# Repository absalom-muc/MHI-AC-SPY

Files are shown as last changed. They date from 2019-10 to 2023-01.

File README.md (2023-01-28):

# MHI-AC-SPY

**This repository is no longer maintained and is therefore archived. An improved version including writing to the air conditioner is [here](https://github.com/absalom-muc/MHI-AC-Ctrl)**

The version here should be only used as a demonstration how to program the HW SPI of the ESP8266 for receiving data.

The program reads data (e.g. room temperature, fan status etc.) from a Mitsubishi Heavy Industries (MHI)
air conditioner (AC) via SPI and sends the data via MQTT. The AC is the SPI master and the ESP8266 is the SPI slave.
So far only reading from the AC is supported. (but writing is planned for the future)
The program has a draft status and your input is welcome.
My target is to read and write data with an ESP8266.

# Attention:
You have to open the indoor unit to have access to the SPI. Opening of the indoor unit should be done by 
a qualified professional because faulty handling may cause leakage of water, electric shock or fire!

# Prerequisites:
For use of the program you have to connect your ESP8266 (I use a LOLIN(WEMOS) D1 R2 & mini with 80 MHz) via a
cable connector to your air conditioner. This has to be a split device (separated indoor and outdoor unit).
I assume that all indoor units of the type SRC xx ZS-S are supported. I use the indoor unit SRK 35 ZS-S and the outdoor unit SRC 35 ZS-S.
  
# Installing:

## Hardware:
The ESP8266 is powered from the AC via DC-DC (12V -> 5V) converter
The ESP8266 SPI signals SCL (SPI clock) and MOSI (Master Out Slave In) signals are connected via a voltage divider with the AC. But after gaining some experiences I recommend to use a voltage level shifter instead of a voltage divider.

## Software:
The program uses the [MQTT client library](https://github.com/knolleary/pubsubclient) from Nick O'Leary (knolleary). Thank you Nick - great work!
Please check his GitHub page to see how to install it.
Dwonload MHI-SPI.ino and adapt ssid, password and the MQTT server data in the row MQTTclient.setServer("ds218p", 1883);

# License
This project is licensed under the MIT License - see the LICENSE.md file for details

# Acknowledgments
The coding of the SPI protocol of the AC is a nightmare. Without [rjdekker's MHI2MQTT](https://github.com/rjdekker/MHI2MQTT) I had no chance to understand the protocol! Unfortunatelly rjdekker is not longer active on GitHub. He used an Arduino plus an ESP8266 for his project.

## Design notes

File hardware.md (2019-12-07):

# Hardware
**After gaining some experience I recommend to use a voltage level shifter instead of the resistor based voltage divider, please see [here](https://github.com/absalom-muc/MHI-AC-Ctrl)**

## Schematic
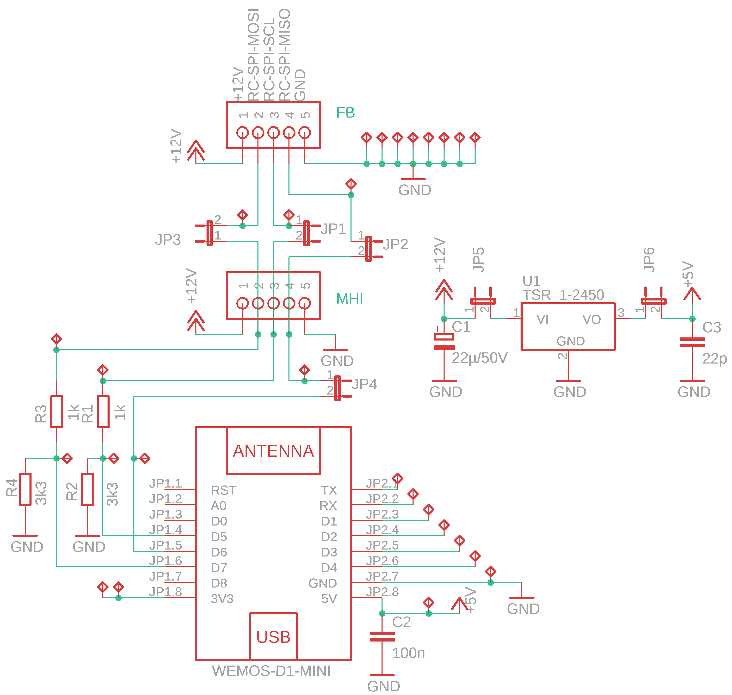
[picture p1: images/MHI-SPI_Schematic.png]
schematic


## Connector
The AC provides the signals via the CNS connector. It has 5 pins with a pitch of 2 mm (0.079''). It is out of the [PH series from JST](http://www.jst-mfg.com/product/detail_e.php?series=199). The position of the connector is visible on the following photo of the indoor unit PCB.
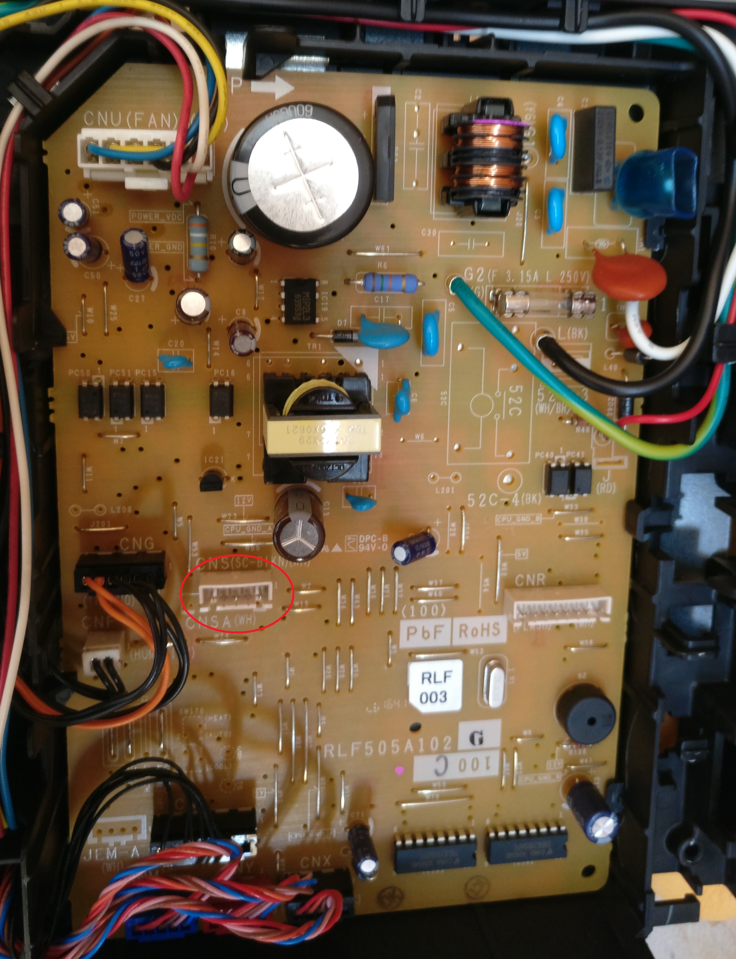
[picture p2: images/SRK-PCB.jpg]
Indoor PCB

**Opening of the indoor unit should be done by a qualified professional because faulty handling may cause leakage of water, electric shock or fire!**

## Power Supply
The connector provides +12V. The DC-DC converter [TSR 1-2450](https://www.tracopower.com/products/browse-by-category/find/tsr-1/3/) is used to convert it to +5V.

## MHI-SPI Testboard
The [Eagle](https://www.autodesk.com/products/eagle/overview) files (schematic & PCB) for the testboard are located in the sub-folder [eagle](/eagle). On the PCB are located many jumper and test pins to enable simple connections to measuring devices.

The following photo shows the assembled testboard.
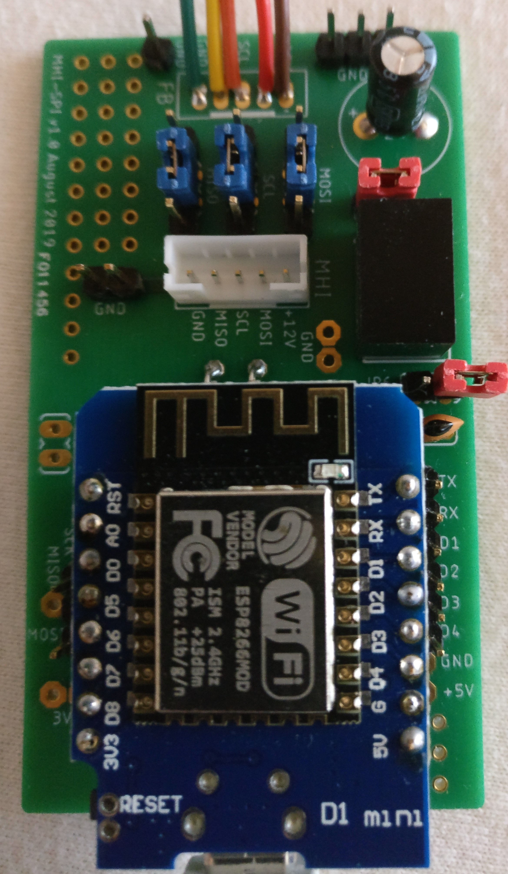
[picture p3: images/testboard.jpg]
Testboard

The upper colored cables are connected to an AC remote control. The JST connector is connected to the MHI AC.

## Signal Connection
SCK is connected via a voltage divider with D5 (GPIO14) and MOSI is connected via a voltage divider with D7 (GPIO13) of ESP8266.

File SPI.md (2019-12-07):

# SPI Bus
**This version is outdated, better check the version [here](https://github.com/absalom-muc/MHI-AC-Ctrl)**
## Interface
The AC is the SPI master and the ESP8266 is the SPI slave. MHI uses the signals SCK, MOSI, MISO.  A slave select signal is not supported.

Name | Function |input/output
------------ | ------------- |--------------
SCK | serial clock | Clock output for AC, input for ESP8266
MOSI | Master Out, Slave In | Data output for MHI, input for ESP8266
MISO | Master In, Slave Out | Input for MHI, output for ESP8266

## Protocol
Clock polarity: CPOL=1 => clock idles at 1, and each cycle consists of a pulse of 0
Clock timing: CPHA=1 => data is captures with the rising clock edge, data changes with the falling edge
## Timing
A byte consists of 8 bits. SCK has a frequency of 32kHz. One bit takes 31.25µs, so one byte takes 8x31.25µs=250µs. There is a pause of 250µs between two bytes.
A frame consists of 20 bytes. A frame consumes 20x2x250µs=10ms. Between 2 frames is a pause of 40ms. So 20 frames per second will be transmitted. The following oscilloscope screenshot shows 3 bytes:
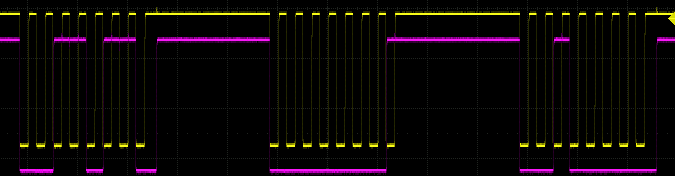
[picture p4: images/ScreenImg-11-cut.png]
SPI timing


Yellow: SCK; Purple: MOSI
# SPI Frame
A frame starts with three signature bytes, followed by 15 data bytes and 2 bytes for a checksum. The following table shows the content of a frame.
## Signature
The MOSI signature bytes indicate the start of a frame with the 3 bytes 0x6c, 0x80, 0x04.
For MISO seems to be more than one signature, usually it is 0xa9, 0x00, 0x07.

## Data
The following clauses describe the MOSI decoding for power, mode, fan, vanes, temperature setpoint and the room temperature
### Power
Power status is coded in MOSI data byte 0 (bit 0).

data byte 0	| Function
---- | -----
Bit 0| Power
0 | off
1 | on

### Mode
The mode is coded in MOSI data byte 0 (bit 4 ... 2).
<table style="width: 273px; height: 68px;">
<thead>
<tr>
<td style="width: 66.9667px;" colspan="3"><strong>data byte 0</strong></td>
<td style="width: 66.9667px;"><strong>Function</strong></td>
</tr>
</thead>
<tbody>
<tr>
<td style="width: 66.9667px;">bit 4</td>
<td style="width: 71.4333px;">bit 3</td>
<td style="width: 66.9667px;">bit 2</td>
<td style="width: 66.9667px;">Mode</td>
</tr>
<tr>
<td style="width: 66.9667px;">0</td>
<td style="width: 71.4333px;">0</td>
<td style="width: 66.9667px;">0</td>
<td style="width: 66.9667px;">Auto</td>
</tr>
<tr>
<td style="width: 66.9667px;">0</td>
<td style="width: 71.4333px;">0</td>
<td style="width: 66.9667px;">1</td>
<td style="width: 66.9667px;">Dry</td>
</tr>
<tr>
<td style="width: 66.9667px;">0</td>
<td style="width: 71.4333px;">1</td>
<td style="width: 66.9667px;">0</td>
<td style="width: 66.9667px;">Cool</td>
</tr>
<tr>
<td style="width: 66.9667px;">0</td>
<td style="width: 71.4333px;">1</td>
<td style="width: 66.9667px;">1</td>
<td style="width: 66.9667px;">Fan</td>
</tr>
<td style="width: 66.9667px;">1</td>
<td style="width: 71.4333px;">0</td>
<td style="width: 66.9667px;">0</td>
<td style="width: 66.9667px;">Heat</td>
</tr>
</tbody>
</table>

### Fan
The fan level is coded in MOSI data byte 1 bit [1:0] and in data byte 6 (bit 6).
<table style="width: 273px; height: 68px;">
<thead>
<tr>
<td style="width: 66.9667px;" colspan="2"><strong>data byte 1</strong></td>
<td style="width: 66.9667px;"><strong>data byte 6</strong></td>
<td style="width: 66.9667px;"><strong>Function</strong></td>
</tr>
</thead>
<tbody>
<tr>
<td style="width: 66.9667px;">bit 1</td>
<td style="width: 71.4333px;">bit 0</td>
<td style="width: 66.9667px;">bit 6</td>
<td style="width: 66.9667px;">Fan</td>
</tr>
<tr>
<td style="width: 66.9667px;">0</td>
<td style="width: 71.4333px;">0</td>
<td style="width: 66.9667px;">0</td>
<td style="width: 66.9667px;">1</td>
</tr>
<tr>
<td style="width: 66.9667px;">0</td>
<td style="width: 71.4333px;">1</td>
<td style="width: 66.9667px;">0</td>
<td style="width: 66.9667px;">2</td>
</tr>
<tr>
<td style="width: 66.9667px;">1</td>
<td style="width: 71.4333px;">0</td>
<td style="width: 66.9667px;">0</td>
<td style="width: 66.9667px;">3</td>
</tr>
<tr>
<td style="width: 66.9667px;">x</td>
<td style="width: 71.4333px;">x</td>
<td style="width: 66.9667px;">1</td>
<td style="width: 66.9667px;">4</td>
</tr>
</tbody>
</table>

### Vanes
The vanes up/down level is coded in MOSI data byte 1 bit [5:4] and in data byte 0 (bit 6).
<table style="width: 273px; height: 68px;">
<thead>
<tr>
<td style="width: 66.9667px;" colspan="2"><strong>data byte 1</strong></td>
<td style="width: 66.9667px;"><strong>data byte 0</strong></td>
<td style="width: 66.9667px;"><strong>Function</strong></td>
</tr>
</thead>
<tbody>
<tr>
<td style="width: 66.9667px;">bit 5</td>
<td style="width: 71.4333px;">bit 4</td>
<td style="width: 66.9667px;">bit 6</td>
<td style="width: 66.9667px;">Vanes (up/down)</td>
</tr>
<tr>
<td style="width: 66.9667px;">0</td>
<td style="width: 71.4333px;">0</td>
<td style="width: 66.9667px;">0</td>
<td style="width: 66.9667px;">1</td>
</tr>
<tr>
<td style="width: 66.9667px;">0</td>
<td style="width: 71.4333px;">1</td>
<td style="width: 66.9667px;">0</td>
<td style="width: 66.9667px;">2</td>
</tr>
<tr>
<td style="width: 66.9667px;">1</td>
<td style="width: 71.4333px;">0</td>
<td style="width: 66.9667px;">0</td>
<td style="width: 66.9667px;">3</td>
</tr>
<tr>
<td style="width: 66.9667px;">1</td>
<td style="width: 71.4333px;">1</td>
<td style="width: 66.9667px;">0</td>
<td style="width: 66.9667px;">4</td>
</tr>
<tr>
<td style="width: 66.9667px;">x</td>
<td style="width: 71.4333px;">x</td>
<td style="width: 66.9667px;">1</td>
<td style="width: 66.9667px;">swing</td>
</tr>
</tbody>
</table>
Vanes status is not updated when using IR remote control!

### Room temperature
The room temperature is coded in MOSI data byte 3, bit [7:0] according to the  formula T[°C]=(db3[7:0]-61)/4
The resolution is 0.25°C. But for displaying the room temperature you shouldn't use this resolution to prevent displaying the toggling of the least significant bit.

### Temperature setpoint
The temperature setpoint is coded in MOSI data byte 2, bit [6:0] according to the formula T[°C]=db2[6:0]/2
The resolution of 0.5°C is supported by the wired remote control [RC-E5](https://www.mhi-mth.co.jp/en/products/pdf/pjz012a087b_german.pdf). The IR remote control supports a resolution of 1°C only.

## Checksum
The checksum is calculated by the sum of the signature bytes plus the databytes. The low byte of the checksum is stored at byte position 18 and the low byte of the checksum is stored at byte position 19. Maximum value of the checksum is 0x0fe1. Therefore bit [7:4] of the checksum high byte is always 0.

## Variants
**The following chapter is in draft status!**
Different variants are possible when a remote control is connected via SPI. The MISO frame (data from RC to MHI-AC) requests data. The variant of the data is identified via MISO-db9. MHI-AC answers with the same value in MOSI-db9 (but only when bit2 of MISO-db14 is set).

The following screenshot shows some SPI traffic:
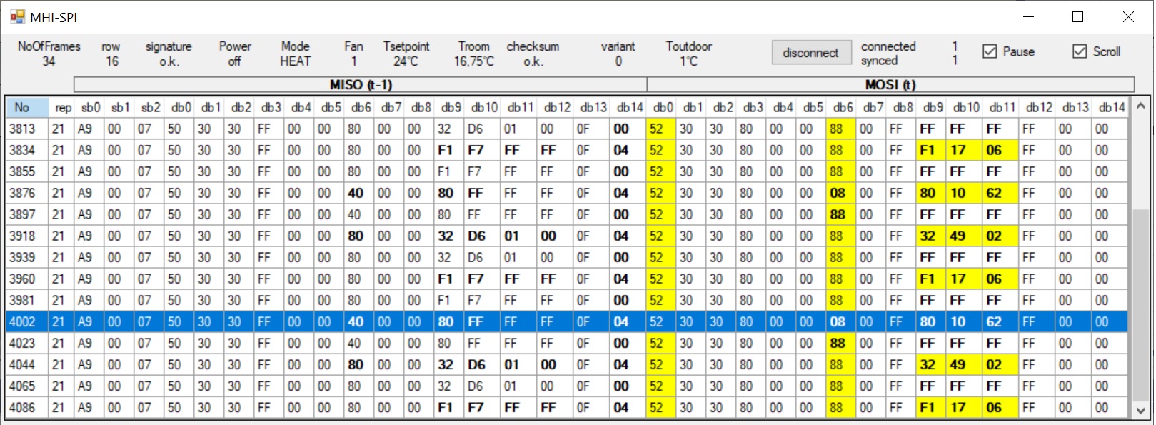
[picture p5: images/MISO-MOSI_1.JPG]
MISO MOSI traffic


In the marked row MISO-db9=0x80 and bit2 of MISO-db14 is set, so variant 0 is selected. MOSI-db9=0x80 and MOSI-db11 represents the outdoor temperature

data byte 9	| Variant | description
---- | ----- | -----
0xff| default | default when no SPI RC is connected or no 'special' data are requested
0x80| 0 | db10=?, Outdoor temperature: T[°C]=(db11[7:0]-94)/4 (formula is not finally confirmed)
0x32| 1 | db10=?, db11=?
0xf1| 2 | db10=?, db11=?
0xd2| 3 | db10=?, db11=?, only seen once during heating

note: the numbering of the variants 0..2 is reused from [rjdekker's code here](https://raw.githubusercontent.com/rjdekker/MHI2MQTT/master/src/MHI-SPI2ESP.ino)

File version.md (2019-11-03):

**Version History of MHI-AC-SPI.ino**

## v1.1
WiFI hostname added
rx_SPIframe replaced by rx_payload and corrected to a length of 19
state machine for sync adapted
toggle of room temperature suppressed

## v1.0
initial

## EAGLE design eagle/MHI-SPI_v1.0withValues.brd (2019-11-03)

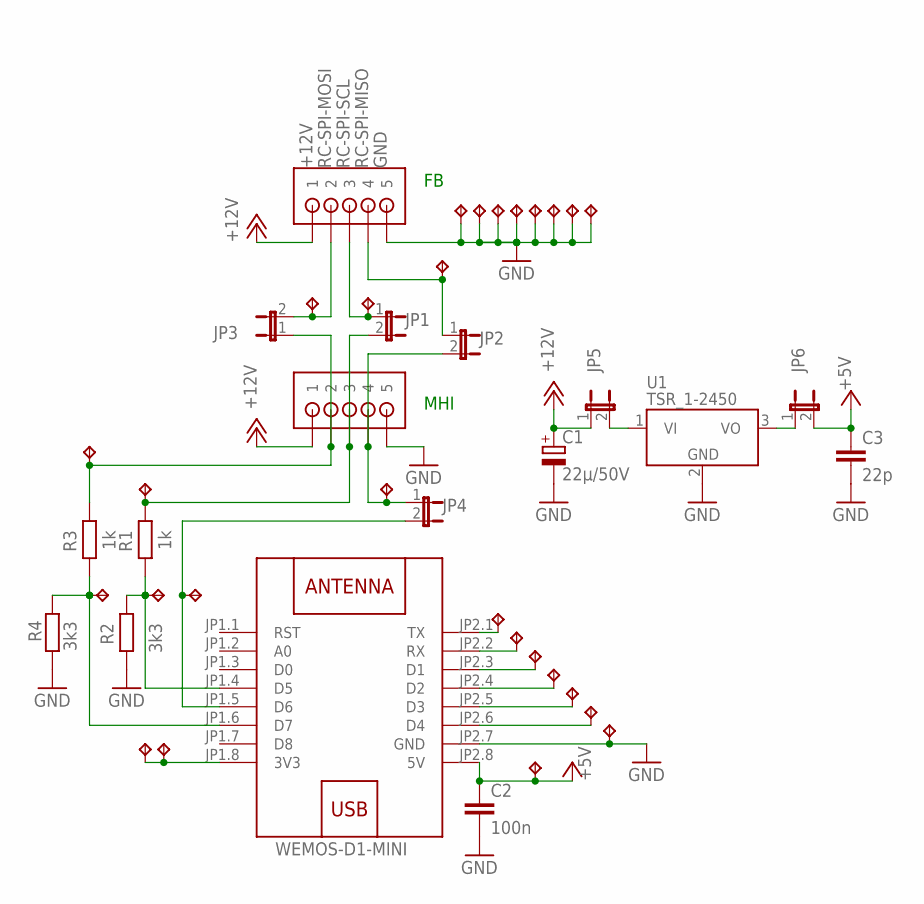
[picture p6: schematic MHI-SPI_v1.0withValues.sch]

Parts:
C1: 22µ/50V; E5-10,5
C2: 100n; C025-024X044
C3: 22p; C025-024X044
JP1, JP2, JP3, JP4, JP5, JP6: JP1E; JP1
R1, R3: 1k; VMTA55
R2, R4: 3k3; VMTA55
TP1, TP2, TP3, TP4, TP5, TP6, TP7, TP8, TP9, TP10, TP11, TP12, TP13, TP14, TP15, TP16, TP17, TP18, TP19, TP20, TP21, TP22, TP23, TP24, TP25, TP26, TP27: TPPAD1-13; P1-13
U1: TSR_1-2450; TSR-1
U$1: WEMOS-D1-MINI
U$4, U$5: JST-PH_5-PIN_HEADER; JST_B5B-PH_HEADER

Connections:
+3V3: TP22.TP, TP23.TP, U$1.JP1.8 (3V3)
+5V: C2.1, C3.1, JP6.2, TP21.TP, U$1.JP2.8 (5V)
+12V: C1.+, JP5.1, U$4.P1 (1), U$5.P1 (1)
D1: TP16.TP, U$1.JP2.3 (D1)
D2: TP17.TP, U$1.JP2.4 (D2)
D3: TP18.TP, U$1.JP2.5 (D3)
D4: TP19.TP, U$1.JP2.6 (D4)
GND: C1.-, C2.2, C3.2, R2.2, R4.1, TP1.TP, TP2.TP, TP3.TP, TP4.TP, TP20.TP, TP24.TP, TP25.TP, TP26.TP, TP27.TP, U1.2 (GND), U$1.JP2.7 (GND), U$4.P5 (5), U$5.P5 (5)
MHI-SPI-MISO: JP2.2, JP4.1, TP8.TP, U$5.P4 (4)
MHI-SPI-MOSI: JP3.1, R3.1, TP10.TP, U$5.P2 (2)
MHI-SPI-SCL: JP1.2, R1.1, TP9.TP, U$5.P3 (3)
MISO: JP4.2, TP11.TP, U$1.JP1.5 (D6)
MOSI: R3.2, R4.2, TP13.TP, U$1.JP1.6 (D7)
unnamed: JP6.1, U1.3 (VO)
RC-SPI-MISO: JP2.1, TP5.TP, U$4.P4 (4)
RC-SPI-MOSI: JP3.2, TP7.TP, U$4.P2 (2)
RC-SPI-SCL: JP1.1, TP6.TP, U$4.P3 (3)
RX: TP15.TP, U$1.JP2.2 (RX)
SCK: R1.2, R2.1, TP12.TP, U$1.JP1.4 (D5)
TX: TP14.TP, U$1.JP2.1 (TX)
VI: JP5.2, U1.1 (VI)

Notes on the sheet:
MHI

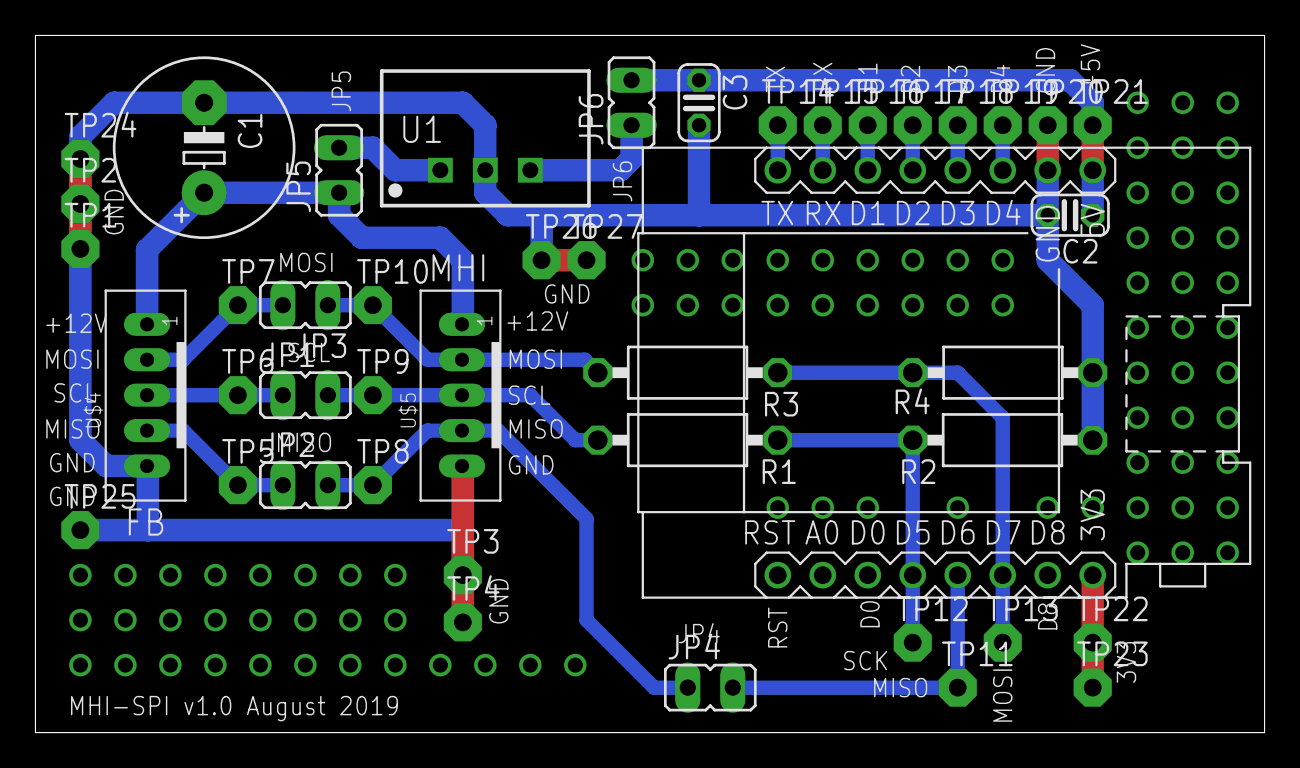
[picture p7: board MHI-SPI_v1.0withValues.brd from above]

Board: 2 copper layers, 69.4 x 39.4 mm, 44 parts (0 on the bottom side), 21 nets.

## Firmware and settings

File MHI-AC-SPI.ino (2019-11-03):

// MHI-AC-SPI v1.1 by absalom-muc
// read data via SPI and send via MQTT

#include "esp8266_peri.h"
#include <ESP8266WiFi.h>
#include <PubSubClient.h> // see https://github.com/knolleary/pubsubclient

const char* ssid = "xxx";
const char* password = "xxx";

WiFiClient espClient;
PubSubClient MQTTclient(espClient);

#define SYNC_PIN 4
volatile bool valid_datapacket_received = false;
volatile bool new_datapacket_received = false;
unsigned long last_sync_isrT = 0;
volatile bool sync = false;
volatile bool sync_changed = true;

unsigned long runtimeMillis = 0;
uint8_t rx_payload[19];

#define SIGNBYTE1 0
#define SIGNBYTE2 1
#define DATABYTE0 SIGNBYTE2 + 1
#define DATABYTE1 SIGNBYTE2 + 2
#define DATABYTE2 SIGNBYTE2 + 3
#define DATABYTE3 SIGNBYTE2 + 4
#define DATABYTE6 SIGNBYTE2 + 7

void MQTTreconnect() {
  while (!MQTTclient.connected()) { // Loop until we're reconnected
    SPI1S |= SPISSRES;   //reset SPI
    update_sync(0);
    Serial.print("Attempting MQTT connection...");
    if (MQTTclient.connect ("MHI-AC-SPI", "MHI/connected", 0, true, "0")) {
      Serial.println("connected");
      MQTTclient.publish("MHI/connected", "1", true);
    } else {
      Serial.print("failed, rc=");
      Serial.print(MQTTclient.state());
      Serial.println(" try again in 5 seconds");
      // Wait 5 seconds before retrying
      delay(5000);
    }
  }
}

void ICACHE_RAM_ATTR sync_isr() {     // Sync pin interrupt on falling edge
  SPI1S |= SPISSRES;                  // SPISSRES=bit31, Reset HSPI slave (SPI_SYNC_RESET )
  SPI1S &= ~SPISSRES;
  SPI1CMD = SPICMDUSR;                // Start HSPI slave with enable user-defined commands
}

void ICACHE_RAM_ATTR _hspi_slave_isr_handler(void *) {
    uint32_t istatus = SPIIR;
    if(istatus & (1 << SPII1)) {      //SPI1 ISR (SPI1 Interrupt)
        uint32_t status = SPI1S;
        SPI1S &= ~(0x3E0);            //disable interrupts
        SPI1S |= SPISSRES;            //reset
        SPI1S &= ~(0x1F);             //clear interrupts
        SPI1S |= (0x3E0);             //enable interrupts

        if(status & SPISWBIS) {       // was it a SPI_SLV_WR_BUF_INT
          uint8_t *p = rx_payload;
          uint32_t dword;
          new_datapacket_received = 0;
          uint16_t sum = 0x6c;
          for(int i=0; i<19;i++) {
            if (i%4 == 0)
              dword = SPI1W(i/4);
            if(*p != (uint8_t)dword)
              new_datapacket_received = 1;
            *p = (uint8_t)dword;
            if(i<17)
              sum += *p;
            p++;
            dword = dword>>8;
          }
          if((rx_payload[0] != 0x80 | rx_payload[1] != 0x04) | (rx_payload[17] != highByte(sum) | rx_payload[18] != lowByte(sum)))
            digitalWrite(SYNC_PIN, 0);  // for debug only
          else
            valid_datapacket_received = true;
          digitalWrite(LED_BUILTIN, LOW);  // for debug only
        }
    } else if(istatus & (1 << SPII0)) { //SPI0 ISR
        SPI0S &= ~(0x3ff);//clear SPI ISR
    } else if(istatus & (1 << SPII2)) {} //I2S ISR
}

void update_sync(bool sync_new) {
  if(sync_new != sync) {
    sync = sync_new;
    sync_changed = true;
    digitalWrite(SYNC_PIN, sync_new);
  }
}

void hspi_slave_begin() {
    pinMode(SCK, SPECIAL);                  // Both inputs in slave mode
    pinMode(MOSI, SPECIAL);
    // Take care, the register descriptions might be wrong! Couldn't find a ESP8266 SPI register description
    SPI1C = 0x0628A000;                     // SPI_CTRL_REG LSB first, single bit rx_payload mode.
                                            // bit 26 = 1 SPI_WR_BIT_ORDER =>  sends LSB first
                                            // bit 25 = 1 SPI_RD_BIT_ORDER =>  sends LSB first
                                            // bit 24 = 0 SPI_FREAD_QIO  =>  no
                                            // bit 23 = 0 SPI_FREAD_DIO => disable
                                            // bit 21 = 1 SPI_WP =>  output high
                                            // bit 20 = 0 SPI_FREAD_QUAD => disable
                                            // die 8 von 0x0628A000 zeigt auf reserved bits
                                            // das oberste bit von A in 0x0628A000 zeigt auf reserved bits
                                            // bit 14 = 0 SPI_FREAD_DUAL => disable
                                            // bit 13 = 1 SPI_FASTRD_MODE => enable
                                            
    SPI1S = SPISE | SPISBE | SPISCD | 0x3E0;// SPI_SLAVE_REG, set slave mode, WR/RD BUF enable, CMD define, enable interrupts
                                            // bit 30 = 1 (SPISE) SPI_SLAVE_MODE => slave mode
                                            // bit 29 = 1 (SPISBE) SPI_SLV_WR_RD_BUF_EN => enables write and read buffer commands in slave mode
                                            // bit 27 = 1 (SPISCD) SPI_SLV_CMD_DEFINE =>  slave mode commands are defined in SPI_SLAVE3
    SPI1U=0x00000040;                       // evtl. SPI_CK_I_EDGE In slave mode, the bit is the same as SPI_CK_OUT_EDGE in master mode. It is combined with SPI_MISO_DELAY_MODE
    SPI1CLK = 0;                            // SPI_CLOCK_REG
    SPI1U1 = 7 << SPILADDR;                 // SPI_USER1_REG, set address length to 8 bits - needed, but meaning is not clear
    SPI1U2 = 7 << SPILCOMMAND;              // SPI_USER2_REG, set command length to 8 bits
    SPI1S1 = (19 * 8 - 1) << SPIS1LBUF;     // SPI_SLAVE1_REG, SPI_SLV_BUF_BITLEN - doesn't really match SPI_SLAVE1_REG description
    SPI1S3 = 0xF1F26CF3;                    // SPI_SLAVE3_REG, SPI_SLV_RDSTA_CMD_VALUE  = 0x6c
    SPI1P = 0x20080000;                     // SPI_PIN_REG, Clock idle high, seems to cause contension on the clock pin if set to idle low.
    ETS_SPI_INTR_ATTACH(_hspi_slave_isr_handler, 0);
    ETS_SPI_INTR_ENABLE();
}

void setup() {
  Serial.begin(115200);
  Serial.println();
  Serial.printf("%lu:MHI-AC_SPI starting\n", millis());
  pinMode(LED_BUILTIN, OUTPUT);  // indicates that a frame was received, active low
  digitalWrite(LED_BUILTIN, HIGH);
  pinMode(SYNC_PIN, OUTPUT);
  digitalWrite(SYNC_PIN, LOW);

  WiFi.hostname("MHI-AC-SPI");
  WiFi.begin(ssid, password);
  Serial.println("");
  while (WiFi.status() != WL_CONNECTED) {
    delay(500);
    Serial.print(".");
  }
  Serial.printf(" connected to %s, IP address: %s\n", ssid, WiFi.localIP().toString().c_str());
  hspi_slave_begin();
  MQTTclient.setServer("ds218p", 1883);
  MQTTreconnect();
}

void loop() {
  uint fan_old = 99;
  uint power_old = 99;
  uint mode_old = 99;
  uint databyte3_old = 99;
  int troom_old = 99;
  uint tsetpoint_old = 99;
  char strtmp[10]; // for the MQTT strings to send
  
  sync_isr();  
  while(1){
    if(valid_datapacket_received) {  // valid frame received
      valid_datapacket_received = false;
      last_sync_isrT = millis();
      sync_isr();        
      update_sync(true);
      digitalWrite(LED_BUILTIN, HIGH);
      if(new_datapacket_received) {  // new frame received
        new_datapacket_received = false;
        MQTTclient.publish("MHI/raw", rx_payload, 19, true);

        if((rx_payload[DATABYTE0] & 0x01) != power_old) {  // Power
          power_old = rx_payload[DATABYTE0] & 0x01;
          if(power_old == 0)
            MQTTclient.publish("MHI/Power", "off", true);
          else
            MQTTclient.publish("MHI/Power", "on", true);
        }
       
        if((rx_payload[DATABYTE0] & 0x1c) != mode_old) {  // Mode
          mode_old = rx_payload[DATABYTE0] & 0x1c;
          switch (mode_old) {
            case 0x00:
                MQTTclient.publish("MHI/Mode", "Auto", true);
                break;
            case 0x04:
                MQTTclient.publish("MHI/Mode", "Dry", true);
                break;
            case 0x08:
                MQTTclient.publish("MHI/Mode", "Cool", true);
                break;
            case 0x0c:
                MQTTclient.publish("MHI/Mode", "Fan", true);
                break;
            case 0x10:
                MQTTclient.publish("MHI/Mode", "Heat", true);
                break;
            default:
                MQTTclient.publish("MHI/Mode", "invalid", true);
                break;
          }
        }

        uint fantmp;
        if((rx_payload[DATABYTE6] & 0x40) > 0) // Fan status
          fantmp = 4;
        else
          fantmp = (rx_payload[DATABYTE1] & 0x03) + 1;
        if(fantmp != fan_old){
          fan_old = fantmp;
          itoa(fan_old, strtmp, 10);
          MQTTclient.publish("MHI/fan", strtmp, true);
        }
          
        if(abs(rx_payload[DATABYTE3] - databyte3_old) > 1) {  // Room temperature delta > 0.25°C
          int troom = (rx_payload[DATABYTE3] - 61) / 4;
          if((rx_payload[DATABYTE3] - 61) % 4 >= 2)
            troom += 1;
          databyte3_old = rx_payload[DATABYTE3];
          if(troom != troom_old) {
            itoa(troom, strtmp, 10);
            MQTTclient.publish("MHI/Troom", strtmp, true);
            troom_old = troom;
          }
        }

        if((rx_payload[DATABYTE2] & 0x7f) >> 1 != tsetpoint_old) {  // Temperature setpoint
          tsetpoint_old = (rx_payload[DATABYTE2] & 0x7f) >> 1;
          itoa(tsetpoint_old, strtmp, 10);
          MQTTclient.publish("MHI/Tsetpoint", strtmp, true);
        }
      }
    }

    if(millis() - last_sync_isrT > 53) {
      last_sync_isrT = millis();
      sync_isr();        
      update_sync(false);
    }
    
    if(sync_changed) {
      if(sync)
        MQTTclient.publish ("MHI/synced", "1", true);
      else
        MQTTclient.publish ("MHI/synced", "0", true);
      sync_changed = 0;
    }

    if (millis() - runtimeMillis > 1000) {
      runtimeMillis+=1000;
      itoa(millis()/1000, strtmp, 10);
      MQTTclient.publish("MHI/runtime", strtmp, true);
    }
    
    if (!MQTTclient.connected())
      MQTTreconnect();
    MQTTclient.loop();
    delay(0);
  }
}

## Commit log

2019-10-27 Create MHI-SPI.ino
    Please consider that it is still a draft
2019-11-03 values for R2/R4 added
    [MHI-SPI_v1.0withValues.brd, MHI-SPI_v1.0withValues.sch]
2019-11-11 Update SPI.md
    Vanes and variants added. Temperature setpoint formular corrected.
2019-12-01 formula for Temperature setpoint corrected

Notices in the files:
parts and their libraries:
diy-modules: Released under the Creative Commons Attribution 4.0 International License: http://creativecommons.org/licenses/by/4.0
